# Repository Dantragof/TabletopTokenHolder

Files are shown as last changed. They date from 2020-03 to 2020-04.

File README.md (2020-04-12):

# What is this?
This is printable token holder for use in tabletop gaming.

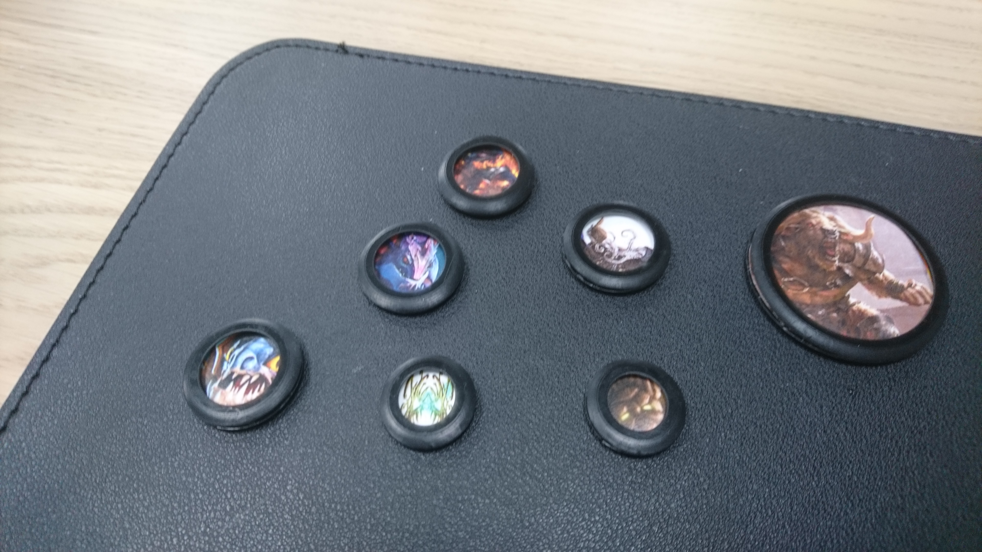
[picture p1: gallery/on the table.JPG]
a bunch of holders


# Why do I need it?
Because you are either:
1) tired of re-using the same monsters just because you have minis
2) running out of storage space for minis
3) dislike collecting paper tokens from all over the room after a door-generated gust of wind
4) dislike using nondescriptive generic tokens like colored circles and squares

# How do I use this?
1) You print, say, five token holders of sizes you need (as many as you will have on the table at the same time)
2) You prepare a stack of paper portraits for all monsters you want in your game (I attached a multilayered Paint.Net project file at https://github.com/Dantragof/TabletopTokenHolder/blob/master/paper%20template/example.pdn , there are cutout layers scaled for a4 borderless printing)
3) You place whatever portraits you want into the token holders
4) You play whatever tabletop you play

# What printers are suitable?
I tested all prototypes and the final token holder using Anycubic Photon S SLA printer using stock Anycubic black resin. I cannot vouch for other printers and resins, but I think most SLA printers will do. I do not know if FDM printers are capable of printing this as I do not have one and I suspect there could be problems due to print size.

# Token sizes
The holders are supposed to represent a certain tabletop game's differently sized creatures: small, medium, and large ones.

Medium holder has an outer radius of 1" (12.7mm radius), and its tokens are supposed to have a radius between 8.76mm and 10.55mm, giving a 1.79mm radial tolerance for a bad scissor technique.

Small holder's respective dimensions are 0.8" / 10.16 mm / 6.22mm / 8.01mm / 1.79mm.

Large holder's respective dimensions are 1.75" / 22.23mm / 18.29mm / 20.08mm / 1.79mm.

# They seem simple, what's the worth of it?
It may take a number of iterations to design token holder that can be printed without major artifacts, feels heavy enough but is not bulky, does not disintegrate on the slightest touch and does not obscure the picture inside. And picture must slide in easily but not fall out easily. Also I'm lasy so it should be printable with minimal postprocessing, so there should be almost no supports, so go redesign this one yet again. And it should work with sloppy cutouts, so overhang should be wide enough to hold a smaller cut paper circle. Oh, it's bulky now and obscures picture in small size, do it over. Oh, the wall is now too thin, it broke during play.

It took me about 30 hours total (15 of them breathing resin fumes) to make these, so hopefully I can save somebody 30 hours of time and some lung capacity so they can play earlier and live longer.

# Notes
1) Wait until covid is done until you gather for play, unless you live with people you play with.
2) Use all standard precautions required for SLA printing, resins are toxic until they are fully cured.

# License
1) Not for commercial use
2) For use in noncommercial projects a reference is required

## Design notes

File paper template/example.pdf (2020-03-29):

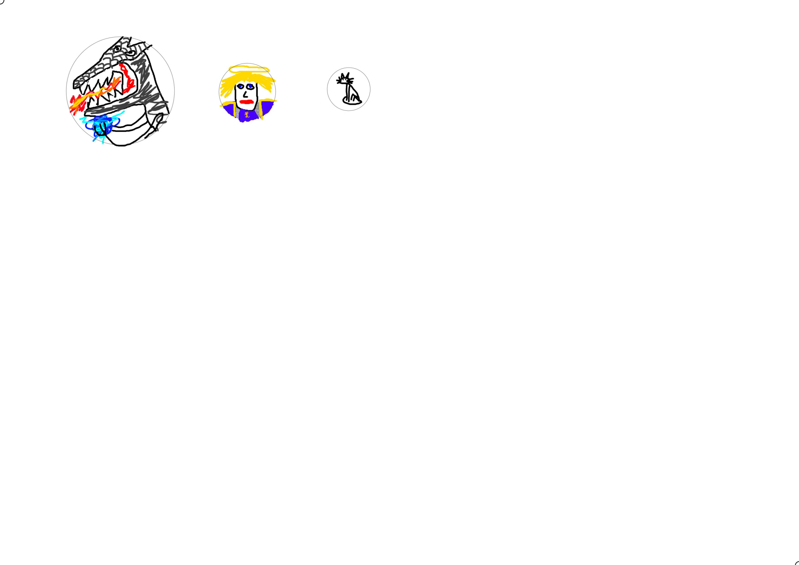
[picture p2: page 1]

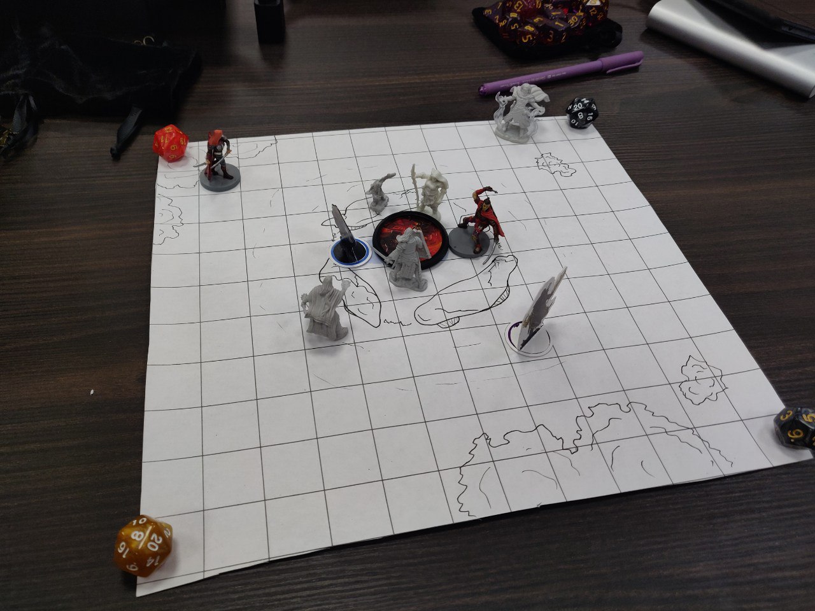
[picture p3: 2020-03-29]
gallery/in play.jpg

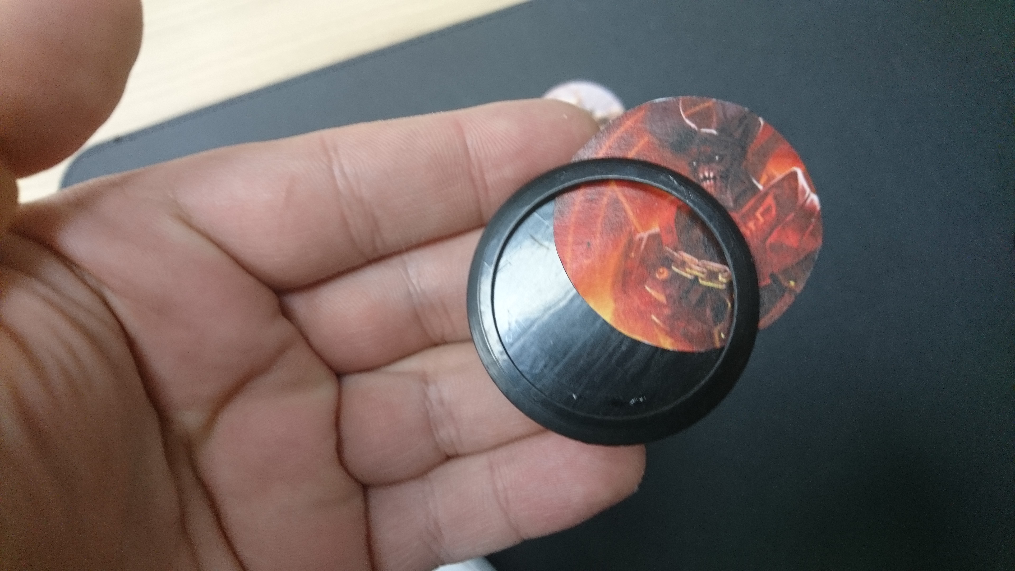
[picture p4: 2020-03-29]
gallery/in hand.JPG

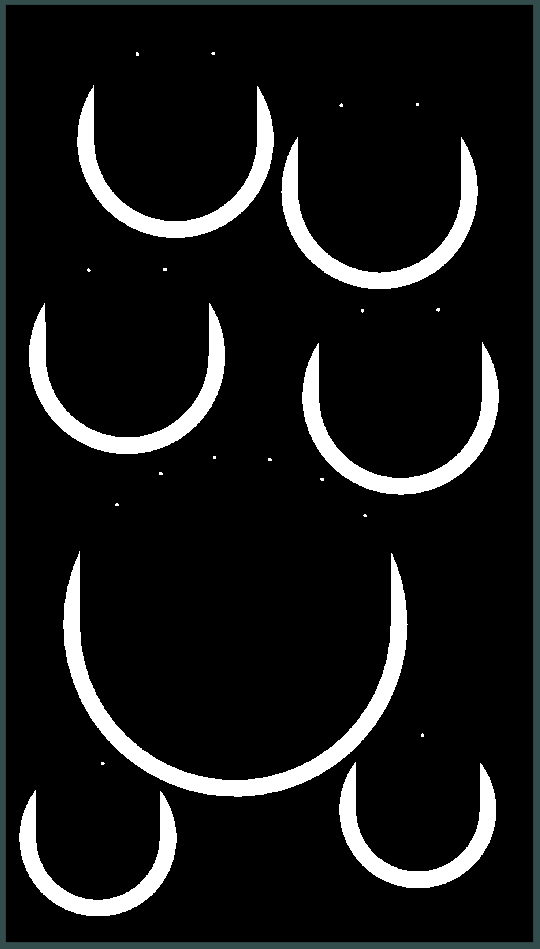
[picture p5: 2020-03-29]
gallery/example of support placement.PNG

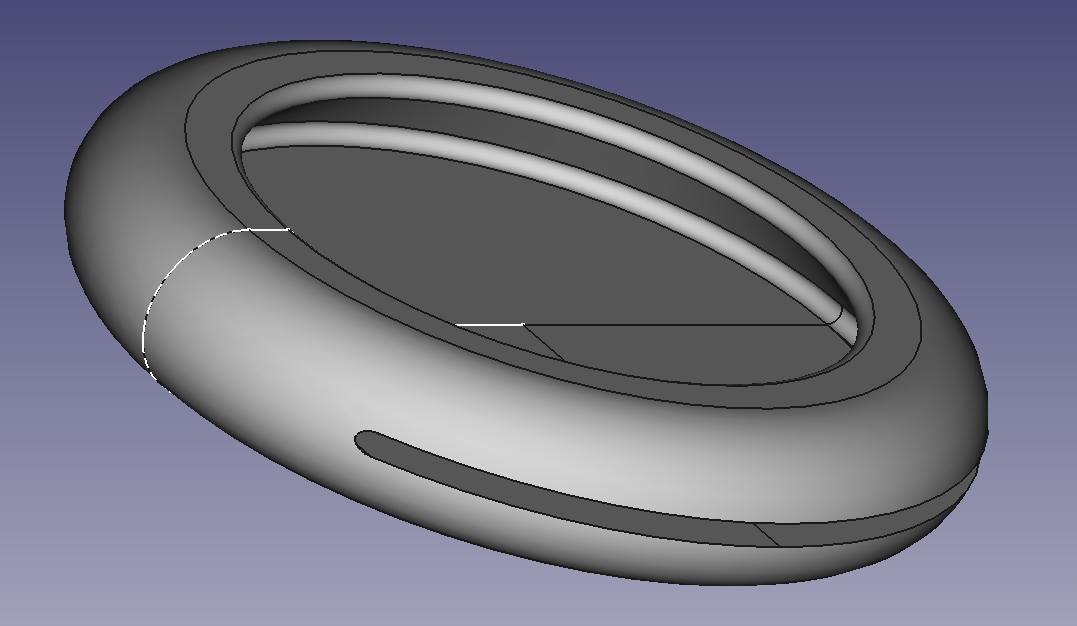
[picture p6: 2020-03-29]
gallery/medium preview.PNG

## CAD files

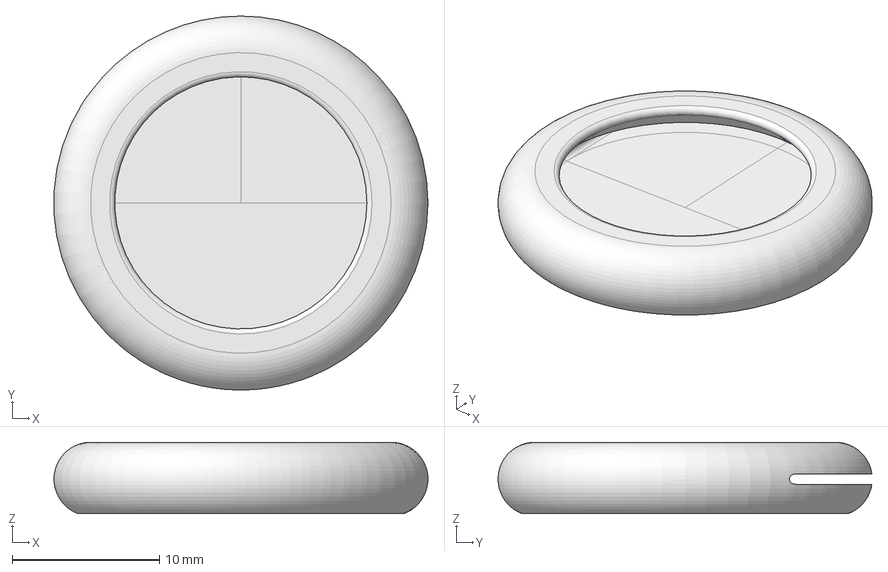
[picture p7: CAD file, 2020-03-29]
freecad sources/medium.FCStd
25.4 x 25.4 x 4.85 mm

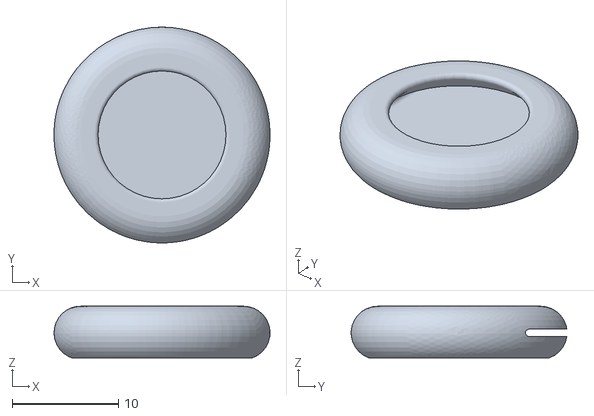
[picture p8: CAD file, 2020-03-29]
STLs/small.stl
20.3 x 20.3 x 4.85

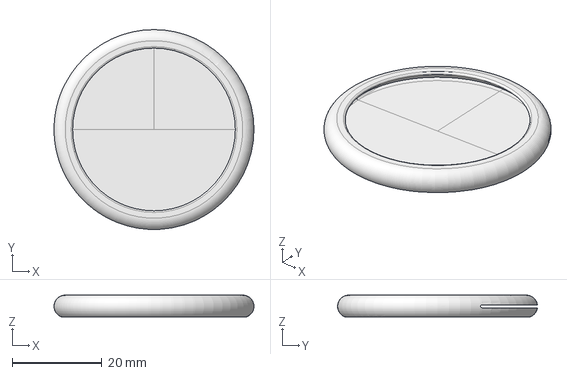
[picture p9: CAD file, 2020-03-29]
freecad sources/large.FCStd
44.5 x 44.4 x 4.85 mm

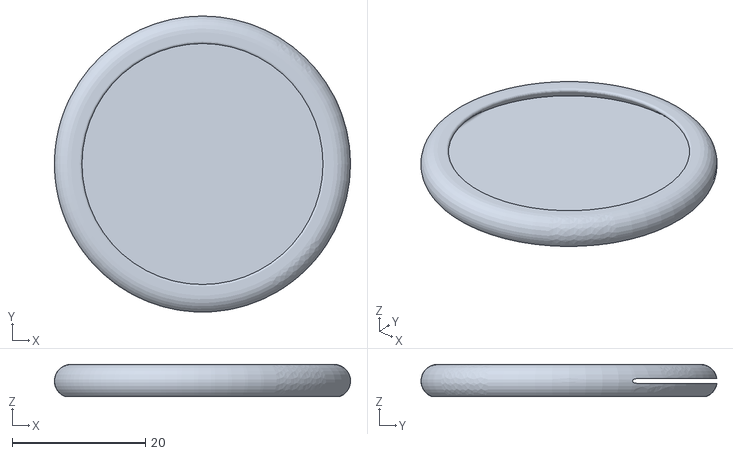
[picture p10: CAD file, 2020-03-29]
STLs/large.stl
44.4 x 44.4 x 4.85

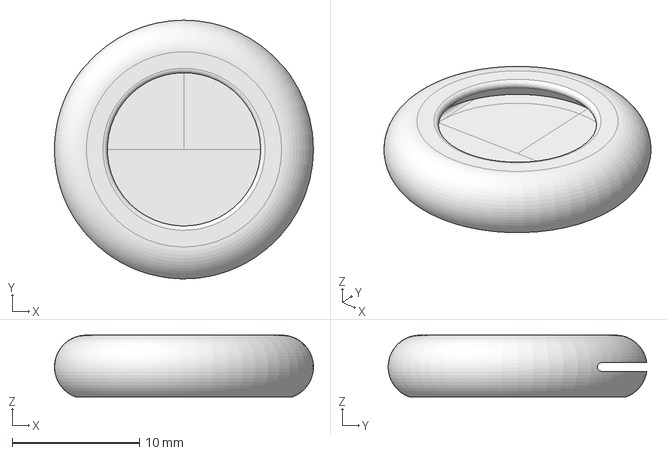
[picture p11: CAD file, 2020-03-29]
freecad sources/small.FCStd
20.3 x 20.3 x 4.85 mm

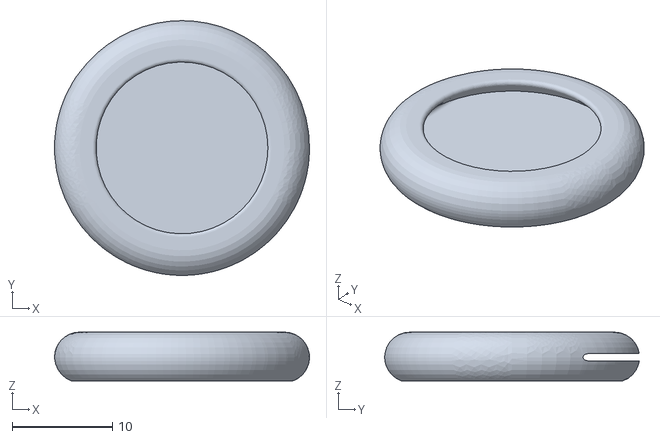
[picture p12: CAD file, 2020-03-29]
STLs/medium.stl
25.4 x 25.4 x 4.85
